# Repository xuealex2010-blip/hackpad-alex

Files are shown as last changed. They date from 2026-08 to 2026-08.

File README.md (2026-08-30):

# CADPAD

A Numberpad with navigation controls with a secondary macro layer. Made to improve my CAD experience.



## Navigation Knob

Featuring navigation accessibility especially for when entering numbers. 

The arrow key outputs give a tactile way to move around the numbers to correct mistakes on the same input device. The tab button also allows for quick navigation between text fields.



## PCB and Schematic Design

The Schematic and PCB can also be viewed HERE >>
https://kicanvas.org/?repo=https%3A%2F%2Fgithub.com%2Fxuealex2010-blip%2Fhackpad-alex%2Ftree%2Fmain%2FPCB

### Schematic Overview

The GPIO pins are optimized to support a larger 4x5 matrix, making this design able to be used for even more projects.

The encoder switch is wired into the matrix to reduce the pins used.



### PCB (GND Fill Hidden)

This design also makes use of 2 special hybrid footprints.

The **Hybrid Switch** footprint supports both MX style and Choc switches, making the design more customizable.

The **Hybrid Diode** which I actually created myself supports common SOD-123 and Through Hole 1N4148 diodes to make it fit the users choice.



### PCB Render



## Case Assembly
Using a sandwich mount for ease of assembly.

The case is also designed with a slight tilt to make the front lip lower to be more comfortable.

The advantage of 3D printing also means that if I want to use different keyswitches, the complex PCB can remain the same, the case can be further customized for that setup.



## Keymap

The layout for the Cadpad follows the common number arrangement of calculators, helping muscle memory carry over.

The `.` and `Enter` keys also utilize QMK's Tap Dance feature.

`.` When double clicked will register a backspace input, this was chosen since a double decimal is not used.

`Enter` acts as the layer modifier when held, accessing the extra function buttons set for macros, as well as common volume controls with the encoder.



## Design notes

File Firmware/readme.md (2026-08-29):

# cadpad

An open source numpad and macropad combination designed for CAD design work.
Sponsored by YSWS program from Hack Club.

Keyboard Maintainer: [Alex](https://github.com/lightgoldsquare-blip)
Hardware Supported: SEEED XIAO RP2040
Hardware Availability: Files available on github: https://github.com/lightgoldsquare-blip

Make example for this keyboard (after setting up your build environment):

    make cadpad:default

Flashing example for this keyboard:

    make cadpad:default:flash

See the [build environment setup](https://docs.qmk.fm/#/getting_started_build_tools) and the [make instructions](https://docs.qmk.fm/#/getting_started_make_guide) for more information. 
## Bootloader

Enter the bootloader in 3 ways:

* **Bootmagic reset**: Hold down the key at (0,0) in the matrix (usually the top left key or Escape) and plug in the keyboard
* **Physical reset button**: Briefly press the button on the back of the PCB - some may have pads you must short instead
* **Keycode in layout**: Press the key mapped to `QK_BOOT` if it is available

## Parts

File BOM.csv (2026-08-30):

Item | Qty
MX Style Switches | 16
1N4148 Diode | 17
SEEED Studio Xiao RP2040 | 1
1x7 Headers | 2
Blank DSA Keycaps | 16
Printed Circuit Board (PCB) | 1
3D Printed Parts | 4
M3x16 Screws | 6
M3 Heat Set Inserts | 6
EC11 Rotary Encoder w/ Push Button | 1

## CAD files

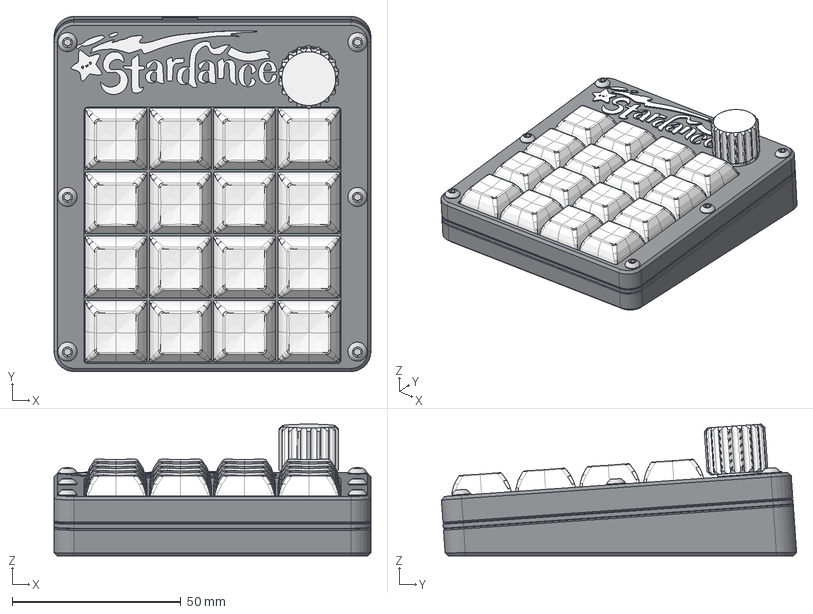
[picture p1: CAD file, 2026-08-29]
CAD/cadpad3Dmodel.step
94.0 x 105.3 x 39.1 mm
Keycap DSA x 16
cadpad_silkscreen x 371
cadpad_pad x 463
cadpad_copper x 127
D_DO-35_SOD27_P7.62mm_Horizontal_5 x 2
D_DO-35_SOD27_P7.62mm_Horizontal_13 x 2
(Unsaved) x 50
D_DO-35_SOD27_P7.62mm_Horizontal_4 x 2
D_DO-35_SOD27_P7.62mm_Horizontal_12 x 2
D_DO-35_SOD27_P7.62mm_Horizontal_3 x 2
D_DO-35_SOD27_P7.62mm_Horizontal_11 x 2
D_DO-35_SOD27_P7.62mm_Horizontal_19 x 2
D_DO-35_SOD27_P7.62mm_Horizontal_2 x 2
D_DO-35_SOD27_P7.62mm_Horizontal_18 x 2
cadpad_via
D_DO-35_SOD27_P7.62mm_Horizontal_9 x 2
D_DO-35_SOD27_P7.62mm_Horizontal x 2
D_DO-35_SOD27_P7.62mm_Horizontal_8 x 2
D_DO-35_SOD27_P7.62mm_Horizontal_16 x 2
cadpad_PCB
D_DO-35_SOD27_P7.62mm_Horizontal_15 x 2
D_DO-35_SOD27_P7.62mm_Horizontal_6 x 2
D_DO-35_SOD27_P7.62mm_Horizontal_14 x 2
Pieza5^Cherry MX__Cortar-Extruir2 x 16
Button M3x16 x 6
Plate
Base
type-c v2:1__Body13
VSS:1__Body1
type-c v2:1__Body14
VDD:1__Body1
main:1__Body14
type-c v2:1__Body15
smd_button v3(Mirror):1__Body2
main:1__Body15
type-c v2:1__Body16
type-c v2:1__Body12
DIN:1__Body1
main:1__Body16
type-c v2:1__Body17
type-c v2:1__Body10
Shell:1__Body1
main:1__Body17
main:1__Body13
type-c v2:1__Body18
type-c v2:1__Body11
DOUT:1__Body1
main:1__Body1
type-c v2:1__Body1
main:1__Body11
main:1__Body3
type-c v2:1__Body2
main:1__Body12
main:1__Body4
type-c v2:1__Body3
type-c v2:1__Body19
main:1__Body5
type-c v2:1__Body4
type-c v2:1__Body20
main:1__Body6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

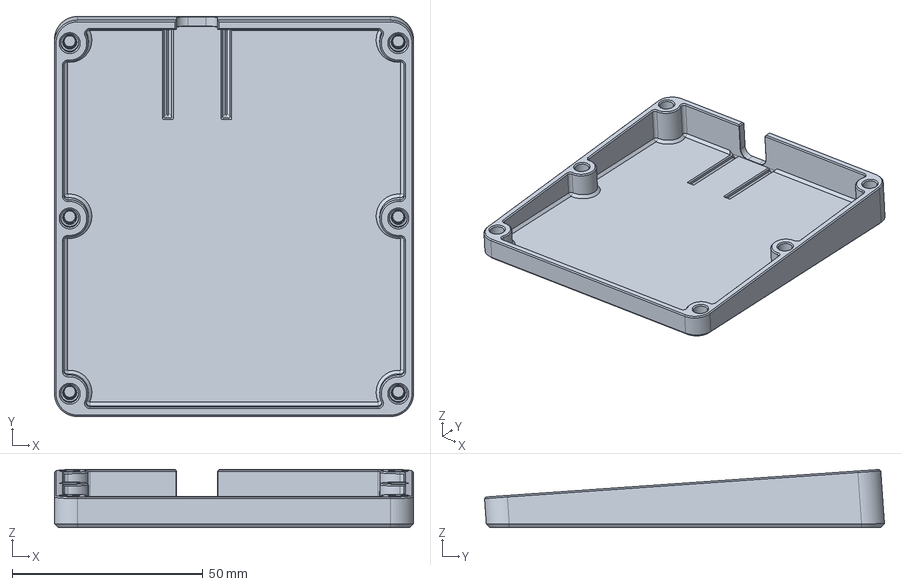
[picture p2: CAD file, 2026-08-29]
production/base.step
94.0 x 104.7 x 15.2 mm

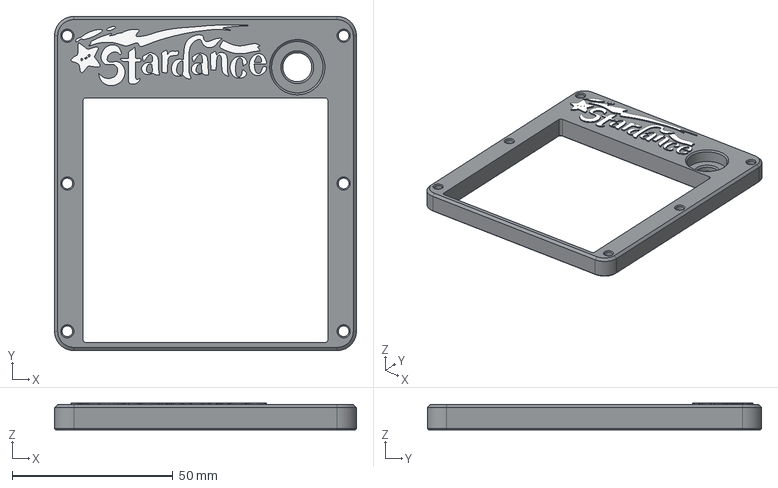
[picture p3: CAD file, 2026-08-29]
production/cover.step
94.0 x 104.0 x 8.40 mm

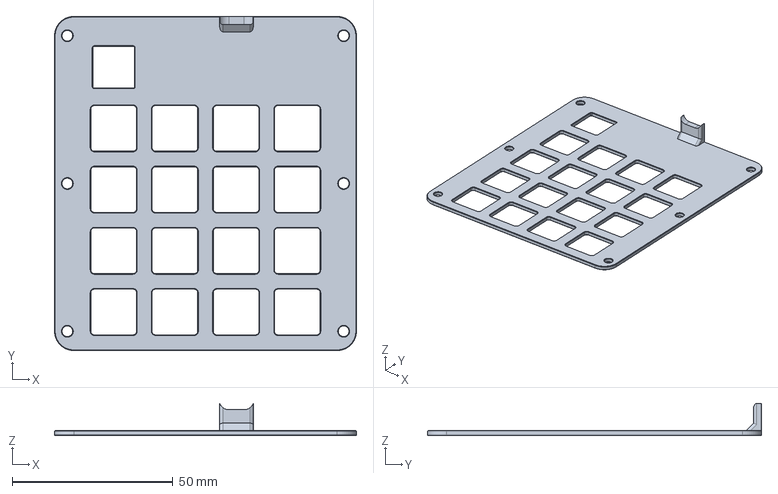
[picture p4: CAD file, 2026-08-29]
production/plate.step
94.0 x 104.0 x 10.1 mm

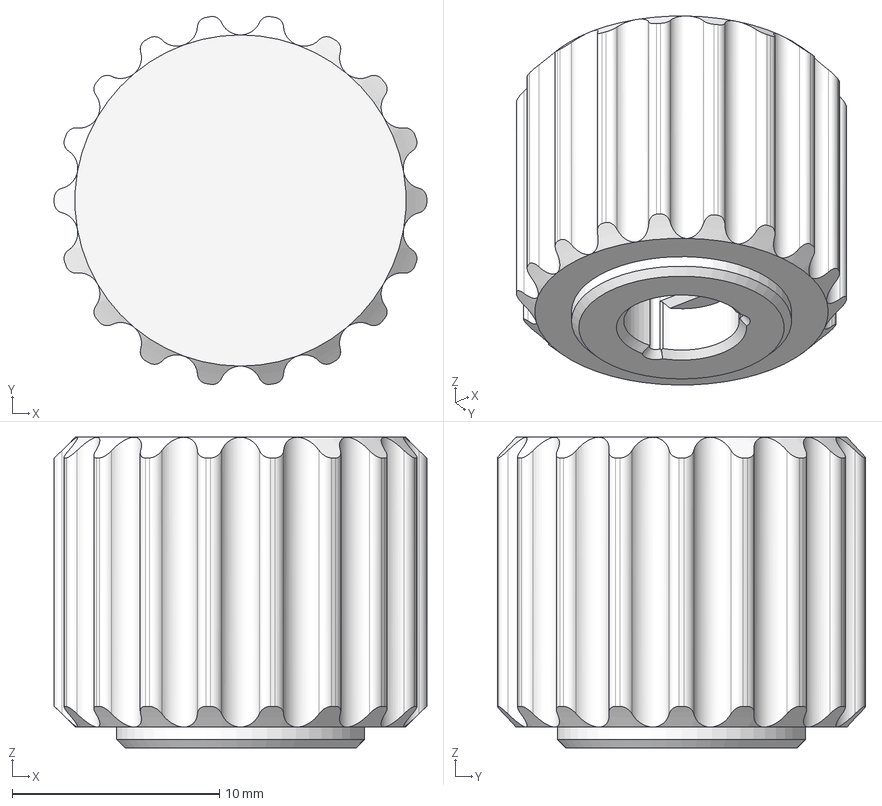
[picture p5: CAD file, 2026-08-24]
production/knob.step
18.0 x 17.8 x 15.0 mm

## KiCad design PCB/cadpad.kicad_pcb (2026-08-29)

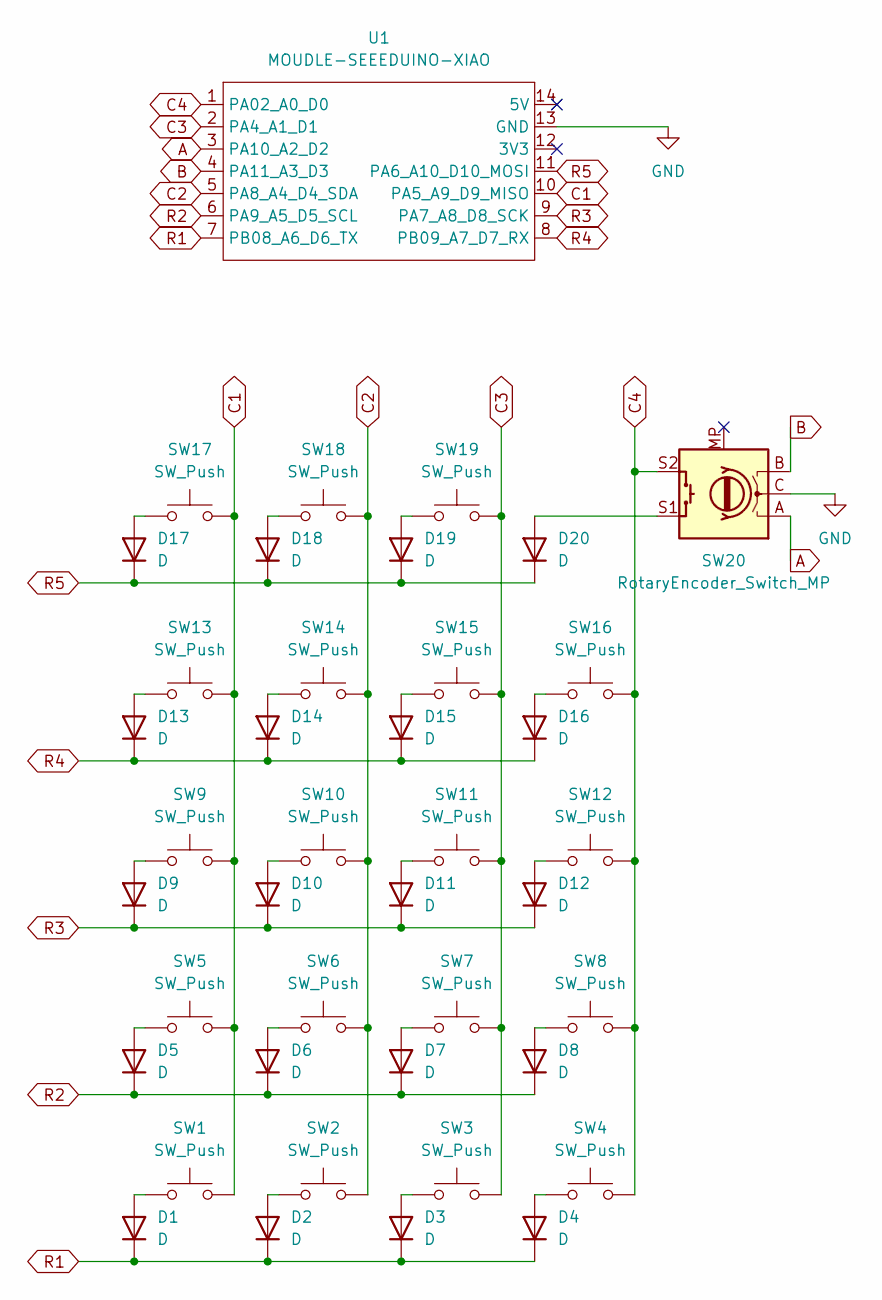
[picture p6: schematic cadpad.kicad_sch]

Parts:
D1, D2, D3, D4, D5, D6, D7, D8, D9, D10, D11, D12, D13, D14, D15, D16, D17, D18, D19, D20: D; D_Combo
SW1, SW2, SW3, SW4, SW5, SW6, SW7, SW8, SW9, SW10, SW11, SW12, SW13, SW14, SW15, SW16, SW17, SW19: SW_Push; SW_Combo_MX_Choc
SW18: SW_Push; SW_Combo_MX_Choc(NoPCBpin)
SW20: RotaryEncoder_Switch_MP; ROT_Alps_EC11E-Switch
U1: MOUDLE-SEEEDUINO-XIAO; XIAO-Generic-Hybrid-14P-2.54-21X17.8MM

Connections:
A: SW20.A, U1.3 (PA10_A2_D2)
B: SW20.B, U1.4 (PA11_A3_D3)
C1: SW1.2, SW5.2, SW9.2, SW13.2, SW17.2, U1.10 (PA5_A9_D9_MISO)
C2: SW2.2, SW6.2, SW10.2, SW14.2, SW18.2, U1.5 (PA8_A4_D4_SDA)
C3: SW3.2, SW7.2, SW11.2, SW15.2, SW19.2, U1.2 (PA4_A1_D1)
C4: SW4.2, SW8.2, SW12.2, SW16.2, SW20.S2, U1.1 (PA02_A0_D0)
GND: SW20.C, U1.13 (GND)
unnamed: D1.2 (A), SW1.1
unnamed: D2.2 (A), SW2.1
unnamed: D3.2 (A), SW3.1
unnamed: D4.2 (A), SW4.1
unnamed: D5.2 (A), SW5.1
unnamed: D6.2 (A), SW6.1
unnamed: D7.2 (A), SW7.1
unnamed: D8.2 (A), SW8.1
unnamed: D9.2 (A), SW9.1
unnamed: D10.2 (A), SW10.1
unnamed: D11.2 (A), SW11.1
unnamed: D12.2 (A), SW12.1
unnamed: D13.2 (A), SW13.1
unnamed: D14.2 (A), SW14.1
unnamed: D15.2 (A), SW15.1
unnamed: D16.2 (A), SW16.1
unnamed: D17.2 (A), SW17.1
unnamed: D18.2 (A), SW18.1
unnamed: D19.2 (A), SW19.1
unnamed: D20.2 (A), SW20.S1
R1: D1.1 (K), D2.1 (K), D3.1 (K), D4.1 (K), U1.7 (PB08_A6_D6_TX)
R2: D5.1 (K), D6.1 (K), D7.1 (K), D8.1 (K), U1.6 (PA9_A5_D5_SCL)
R3: D9.1 (K), D10.1 (K), D11.1 (K), D12.1 (K), U1.9 (PA7_A8_D8_SCK)
R4: D13.1 (K), D14.1 (K), D15.1 (K), D16.1 (K), U1.8 (PB09_A7_D7_RX)
R5: D17.1 (K), D18.1 (K), D19.1 (K), D20.1 (K), U1.11 (PA6_A10_D10_MOSI)

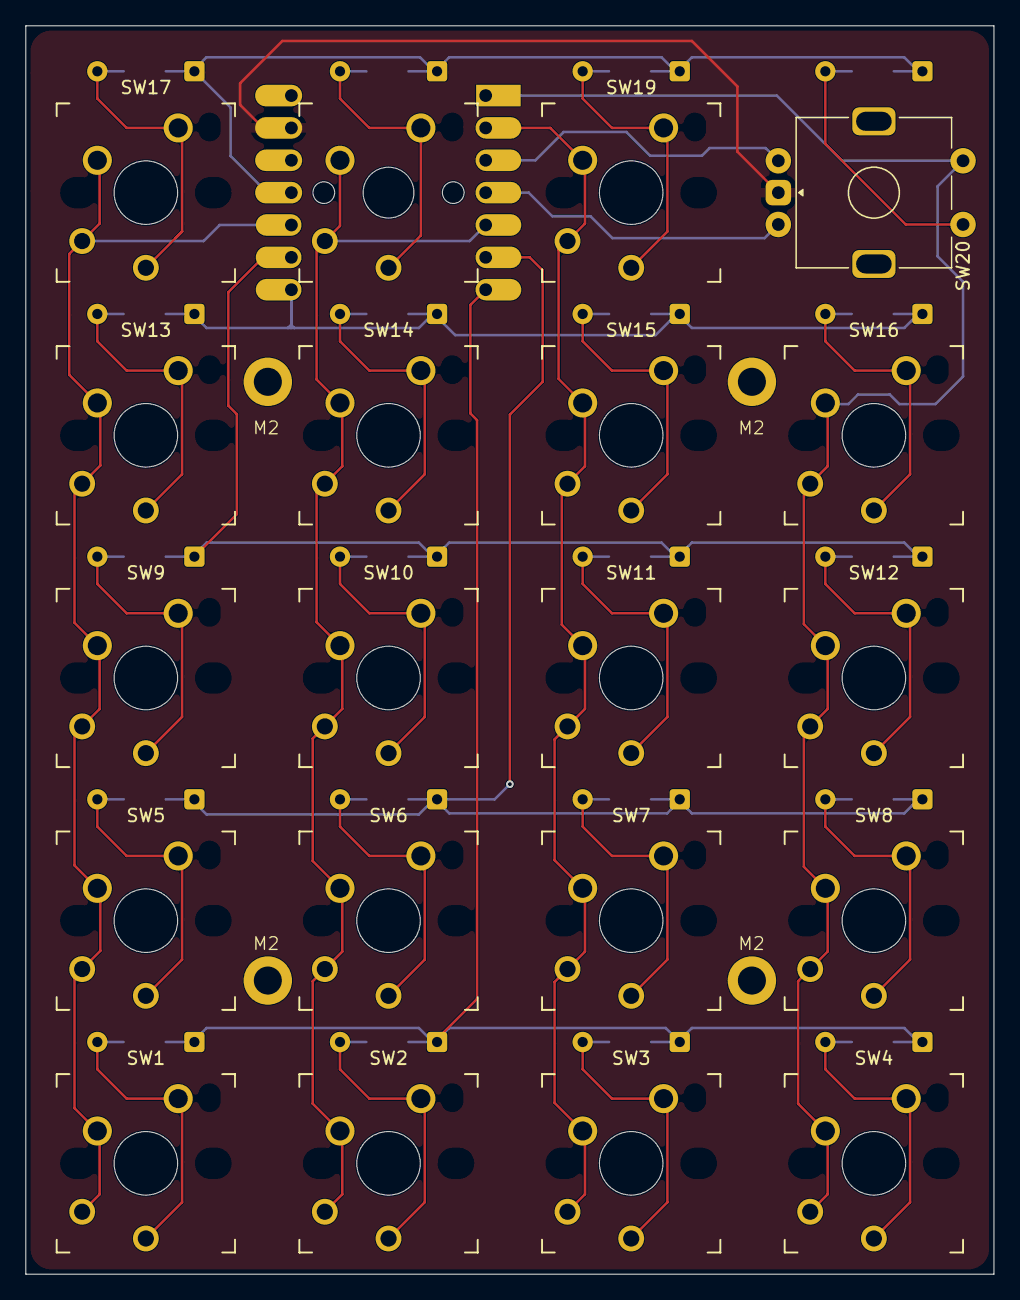
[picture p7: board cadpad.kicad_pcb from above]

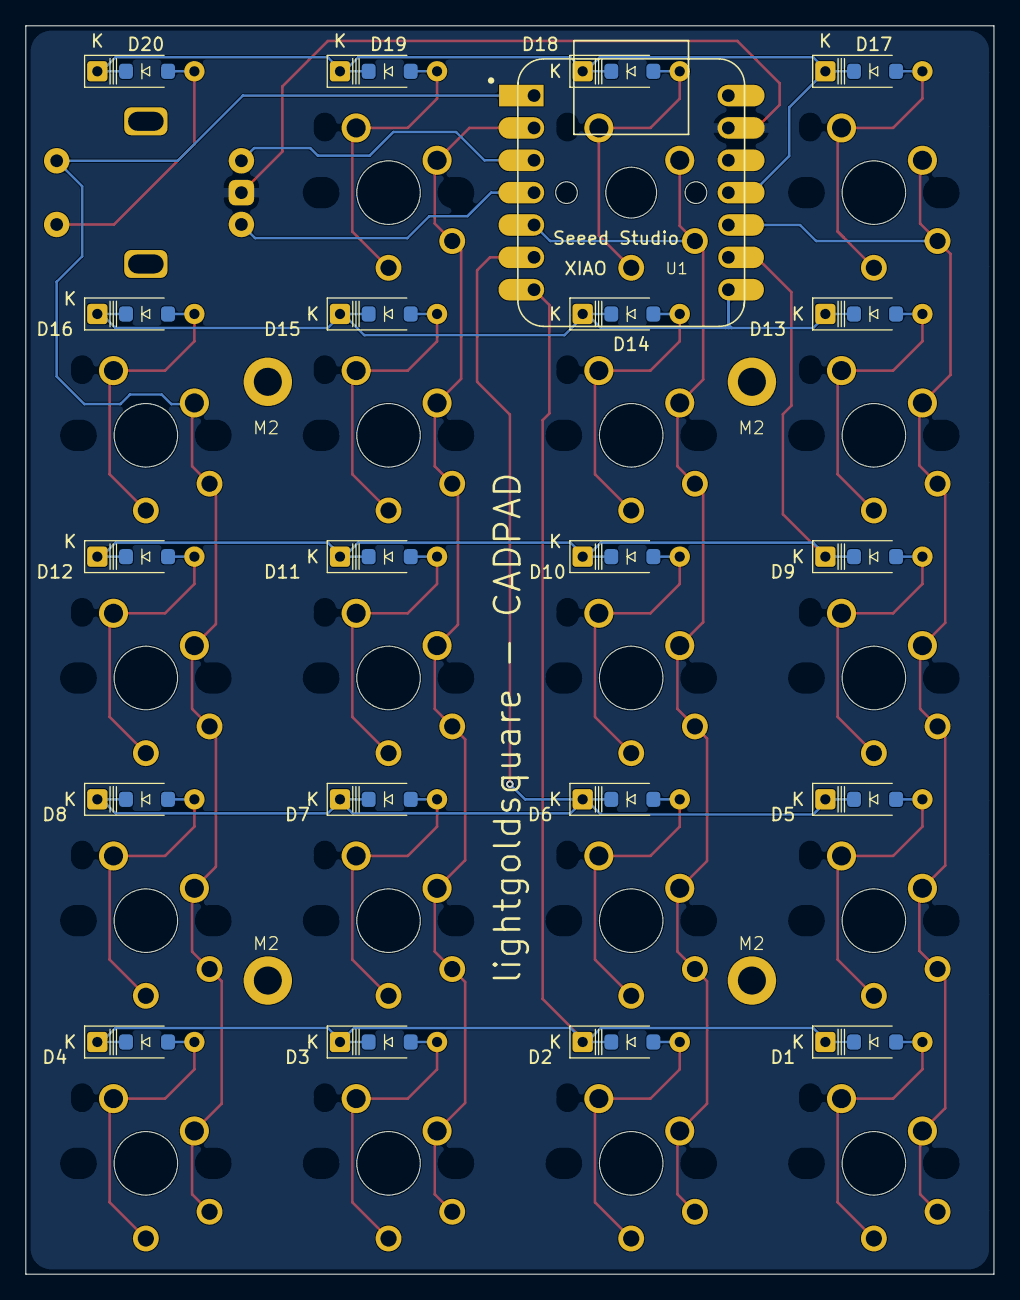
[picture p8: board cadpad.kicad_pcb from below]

Board: 2 copper layers, 76.0 x 98.0 mm, 45 parts (21 on the bottom side), 32 nets.

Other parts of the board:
M2, M2#2, M2#3, M2#4: MountingHole_2.2mm_M2_DIN965_Pad

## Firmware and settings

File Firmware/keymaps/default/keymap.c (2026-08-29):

// Copyright 2023 QMK
// SPDX-License-Identifier: GPL-2.0-or-later

#include QMK_KEYBOARD_H




// Tap Dance declarations
enum {
    TD_DOT_ENTER,
};

//Tap and Double Tap Code
// Tap Dance definitions
tap_dance_action_t tap_dance_actions[] = {
    // Tap once for DOT, twice for backspace
    [TD_DOT_ENTER] = ACTION_TAP_DANCE_DOUBLE(KC_DOT, KC_ENTER),
};



//Tap and Hold Code
typedef struct {
    uint16_t tap;
    uint16_t hold;
    uint16_t held;
} tap_dance_tap_hold_t;

void tap_dance_tap_hold_finished(tap_dance_state_t *state, void *user_data) {
    tap_dance_tap_hold_t *tap_hold = (tap_dance_tap_hold_t *)user_data;

    if (state->pressed) {
        if (state->count == 1
            #ifndef PERMISSIVE_HOLD
            && !state->interrupted
            #endif
        ) {
            register_code16(tap_hold->hold);
            tap_hold->held = tap_hold->hold;
        } else {
            register_code16(tap_hold->tap);
            tap_hold->held = tap_hold->tap;
        }
    }
}

void tap_dance_tap_hold_reset(tap_dance_state_t *state, void *user_data) {
    tap_dance_tap_hold_t *tap_hold = (tap_dance_tap_hold_t *)user_data;

    if (tap_hold->held) {
        unregister_code16(tap_hold->held);
        tap_hold->held = 0;
    }
}

#define ACTION_TAP_DANCE_TAP_HOLD(tap, hold)                                        \
{                                                                               \
    .fn        = {NULL, tap_dance_tap_hold_finished, tap_dance_tap_hold_reset}, \
    .user_data = (void *)&((tap_dance_tap_hold_t){tap, hold, 0}),               \
}

tap_dance_action_t tap_dance_actions[] = {
    [TAP_HOLD] = ACTION_TAP_DANCE_TAP_HOLD(KC_BACKSPACE, MO(1)),
};

bool process_record_user(uint16_t keycode, keyrecord_t *record) {
    tap_dance_action_t *action;
    tap_dance_state_t* state;

    switch (keycode) {
        case TD(TAP_HOLD):
            action = tap_dance_get(QK_TAP_DANCE_GET_INDEX(keycode));
            state = tap_dance_get_state(QK_TAP_DANCE_GET_INDEX(keycode));
            if (!record->event.pressed && state != NULL && state->count && !state->finished) {
                tap_dance_tap_hold_t *tap_hold = (tap_dance_tap_hold_t *)action->user_data;
                tap_code16(tap_hold->tap);
            }
    }
    return true;
}


//Encoder Setup
#if defined(ENCODER_MAP_ENABLE)
const uint16_t PROGMEM encoder_map[][NUM_DIRECTIONS] = {
    [0] = { ENCODER_CCW_CW(KC_LEFT, KC_RIGHT)},
    [1] = { ENCODER_CCW_CW(KC_VOLU, KC_VOLD)},
};
#endif

//Standard Matrix
const uint16_t PROGMEM keymaps[][MATRIX_ROWS][MATRIX_COLS] = {
    /*
     * ┌───┬───┬───┬───┐
     * │   │   │   │TAB│
     * ├───┼───┼───┼───┤
     * │ 7 │ 8 │ 9 │ / │
     * ├───┼───┼───┼───┤
     * │ 4 │ 5 │ 6 │ * │
     * ├───┼───┼───┼───┤
     * │ 1 │ 2 │ 3 │ - │
     * ├───┼───┼───┼───┤
     * │ 0 │___│___│ + │
     * └───┴───┴───┴───┘
     */
    [0] = LAYOUT_numpad_5x4(
        KC_NO, KC_NO, KC_NO, KC_TAB,
        KC_7,   KC_8, KC_9, KC_SLSH,
        KC_4,   KC_5,   KC_6, KC_ASTR,
        KC_1,   KC_2,   KC_3,   KC_MINS,
        KC_0,   TD(TD_DOT_BACKSPACE),   _______, KC_PLUS
    ),

    /*
     * ┌───┬───┬───┬───┐
     * │   │   │   │MTE│
     * ├───┼───┼───┼───┤
     * │F13│F14│F15│F16│
     * ├───┼───┼───┼───┤
     * │F17│F18│F19│F20│
     * ├───┼───┼───┼───┤
     * │F21│F22│F23│F24│
     * ├───┼───┼───┼───┤
     * │BKS│___│___│   │
     * └───┴───┴───┴───┘
     */
    [1] = LAYOUT_numpad_5x4(
        KC_NO,  KC_NO,    KC_NO,  KC_MUTE,
        KC_F13, KC_F14,   KC_F15, KC_F16
        KC_F17, KC_F18,   KC_F19, KC_F20,
        KC_F21, KC_F22,   KC_F23, KC_F24,
        KC_NO, KC_NO,  _______, KC_NO
    )
};

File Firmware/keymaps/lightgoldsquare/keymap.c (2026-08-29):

// Copyright 2023 QMK
// SPDX-License-Identifier: GPL-2.0-or-later

#include QMK_KEYBOARD_H




// Tap Dance declarations
enum {
    TD_DOT_ENTER,
    QUOT_LAYR
};



// Define a type for as many tap dance states as you need
typedef enum {
    TD_NONE,
    TD_UNKNOWN,
    TD_SINGLE_TAP,
    TD_SINGLE_HOLD,
} td_state_t;

typedef struct {
    bool is_press_action;
    td_state_t state;
} td_tap_t;


// Declare the functions to be used with your tap dance key(s)

// Function associated with all tap dances
td_state_t cur_dance(tap_dance_state_t *state);

// Functions associated with individual tap dances
void ql_finished(tap_dance_state_t *state, void *user_data);
void ql_reset(tap_dance_state_t *state, void *user_data);




//Encoder Setup
#if defined(ENCODER_MAP_ENABLE)
const uint16_t PROGMEM encoder_map[][NUM_DIRECTIONS] = {
    [0] = { ENCODER_CCW_CW(KC_LEFT, KC_RIGHT)},
    [1] = { ENCODER_CCW_CW(KC_VOLU, KC_VOLD)},
};
#endif

//Standard Matrix
const uint16_t PROGMEM keymaps[][MATRIX_ROWS][MATRIX_COLS] = {
    /*
     *             ┌───┐
     *             │TAB│
     * ┌───┬───┬───┼───┤
     * │ 7 │ 8 │ 9 │ / │
     * ├───┼───┼───┼───┤
     * │ 4 │ 5 │ 6 │ * │
     * ├───┼───┼───┼───┤
     * │ 1 │ 2 │ 3 │ - │
     * ├───┼───┼───┼───┤
     * │ 0 │___│___│ + │
     * └───┴───┴───┴───┘
     */
    [0] = LAYOUT_numpad_5x4(
        KC_NO,  KC_NO,              KC_NO,     KC_TAB,
        KC_7,   KC_8,               KC_9,      KC_SLSH,
        KC_4,   KC_5,               KC_6,      KC_ASTR,
        KC_1,   KC_2,               KC_3,      KC_MINS,
        KC_0,   TD(TD_DOT_ENTER),   QUOT_LAYR, KC_PLUS
    ),

    /*
     *             ┌───┐
     *             │MTE│
     * ┌───┬───┬───┼───┤
     * │F13│F14│F15│F16│
     * ├───┼───┼───┼───┤
     * │F17│F18│F19│F20│
     * ├───┼───┼───┼───┤
     * │F21│F22│F23│F24│
     * ├───┼───┼───┼───┤
     * │BKS│___│___│   │
     * └───┴───┴───┴───┘
     */
    [1] = LAYOUT_numpad_5x4(
        KC_NO,  KC_NO,    KC_NO,   KC_MUTE,
        KC_F13, KC_F14,   KC_F15,  KC_F16,
        KC_F17, KC_F18,   KC_F19,  KC_F20,
        KC_F21, KC_F22,   KC_F23,  KC_F24,
        KC_NO,  KC_NO,    KC_TRNS, KC_NO
    )
};


//More Tap and Hold Layer Code

// Determine the current tap dance state
td_state_t cur_dance(tap_dance_state_t *state) {
    if (state->count == 1) {
        if (!state->pressed) return TD_SINGLE_TAP;
        else return TD_SINGLE_HOLD;
    }
    else return TD_UNKNOWN;
}

// Initialize tap structure associated with example tap dance key
static td_tap_t ql_tap_state = {
    .is_press_action = true,
    .state = TD_NONE
};

// Functions that control what our tap dance key does
void ql_finished(tap_dance_state_t *state, void *user_data) {
    ql_tap_state.state = cur_dance(state);
    switch (ql_tap_state.state) {
        case TD_SINGLE_TAP:
            tap_code(KC_BACKSPACE);
            break;
        case TD_SINGLE_HOLD:
            layer_on(1);
            break;
        default:
            break;
    }
}

void ql_reset(tap_dance_state_t *state, void *user_data) {
    // If the key was held down and now is released then switch off the layer
    if (ql_tap_state.state == TD_SINGLE_HOLD) {
        layer_off(1);
    }
    ql_tap_state.state = TD_NONE;
}

// Associate our tap dance key with its functionality
tap_dance_action_t tap_dance_actions[] = {
    [QUOT_LAYR] = ACTION_TAP_DANCE_FN_ADVANCED(NULL, ql_finished, ql_reset),
    [TD_DOT_ENTER] = ACTION_TAP_DANCE_DOUBLE(KC_DOT, KC_ENTER)
};

// Set a long-ish tapping term for tap-dance keys
uint16_t get_tapping_term(uint16_t keycode, keyrecord_t *record) {
    switch (keycode) {
        case QK_TAP_DANCE ... QK_TAP_DANCE_MAX:
            return 175;
        default:
            return TAPPING_TERM;
    }
}
